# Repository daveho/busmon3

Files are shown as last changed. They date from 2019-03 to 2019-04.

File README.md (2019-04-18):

# busmon3: Breadboard-friendly 16 bit hex display

`busmon3` is a 16 bit hex display designed to plug into standard 830 contact solderless breadboards.  It's useful for microcomputer projects and similar because it allows you to see the value being driven on a 16 bit bus.

Obligatory action shot (click for full size):

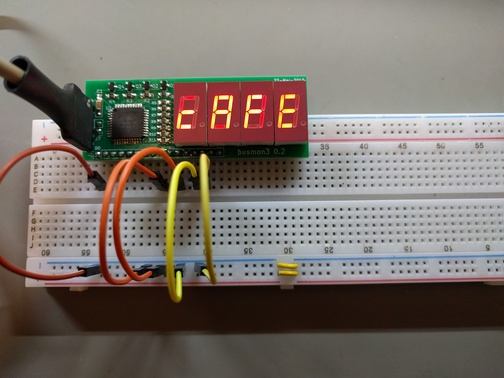
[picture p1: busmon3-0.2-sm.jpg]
Picture of busmon3


I got the idea from Quinn Dunki's [HexOut](http://quinndunki.com/blondihacks/?p=610) project.

The design is fairly brute force, but it does work.  The TQFN44 package of the atmega164a has 0.8mm pitch, which isn't too bad to hand-solder.  I have ordered boards from both [OSHPark](https://oshpark.com/) and [Seeed Studio](https://www.seeedstudio.com/fusion_pcb.html) and they work fine.

Note that the data inputs are pulled high (to VCC) by the atmega164a's internal pullup resistors.  You could change this in the firmware if you felt like it (e.g., because your bus already has external pullup or pulldown resistors.)

Also note that the board (1) is designed to sit at the top of an 830 contact breadboard, (2) assumes that VCC are GND are available on the breadboard's bus strips, and (3) assumes that the bottom bus strip is VCC.

# Parts needed

* atmega164a (TQFN44 package)
* 4 DIP14 package common anode 7 segment LED displays (MAN3620A, LTS-4910AHR, or similar)
* 4 SOT-23 MMBT3906 transistors
* 1 0.1uF 0805 ceramic capacitor (for decoupling)
* 7 270 Ohm 0805 resistors (the schematic shows 330 Ohm, but the displays are driven at 1/4 duty)
* 4 4.7K Ohm 0805 resistors
* 2 pin 0.1" male pin header (for breadboard power connections)
* 6 pin 0.1" male pin header (AVR programming header)
* 16 pin 0.1" male pin header (for breadboard data connections)

You will need an AVR programmer to program the firmware to the atmega164a.

# License

All material is copyright (c) 2017–2019, [David Hovemeyer](mailto:david.hovemeyer@gmail.com).

The hardware design is made available under the [CERN Open Hardware License version 1.2](https://www.ohwr.org/project/cernohl/uploads/505f27c2a8a10e528b079be3c9d876c5/cern_ohl_v_1_2.txt).

The firmware is made available under the [MIT License](https://opensource.org/licenses/MIT).

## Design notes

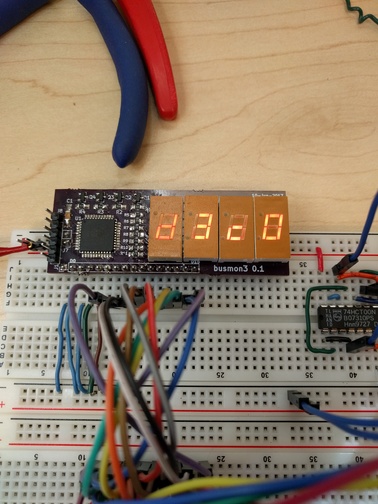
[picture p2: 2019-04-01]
busmon3-sm.jpg

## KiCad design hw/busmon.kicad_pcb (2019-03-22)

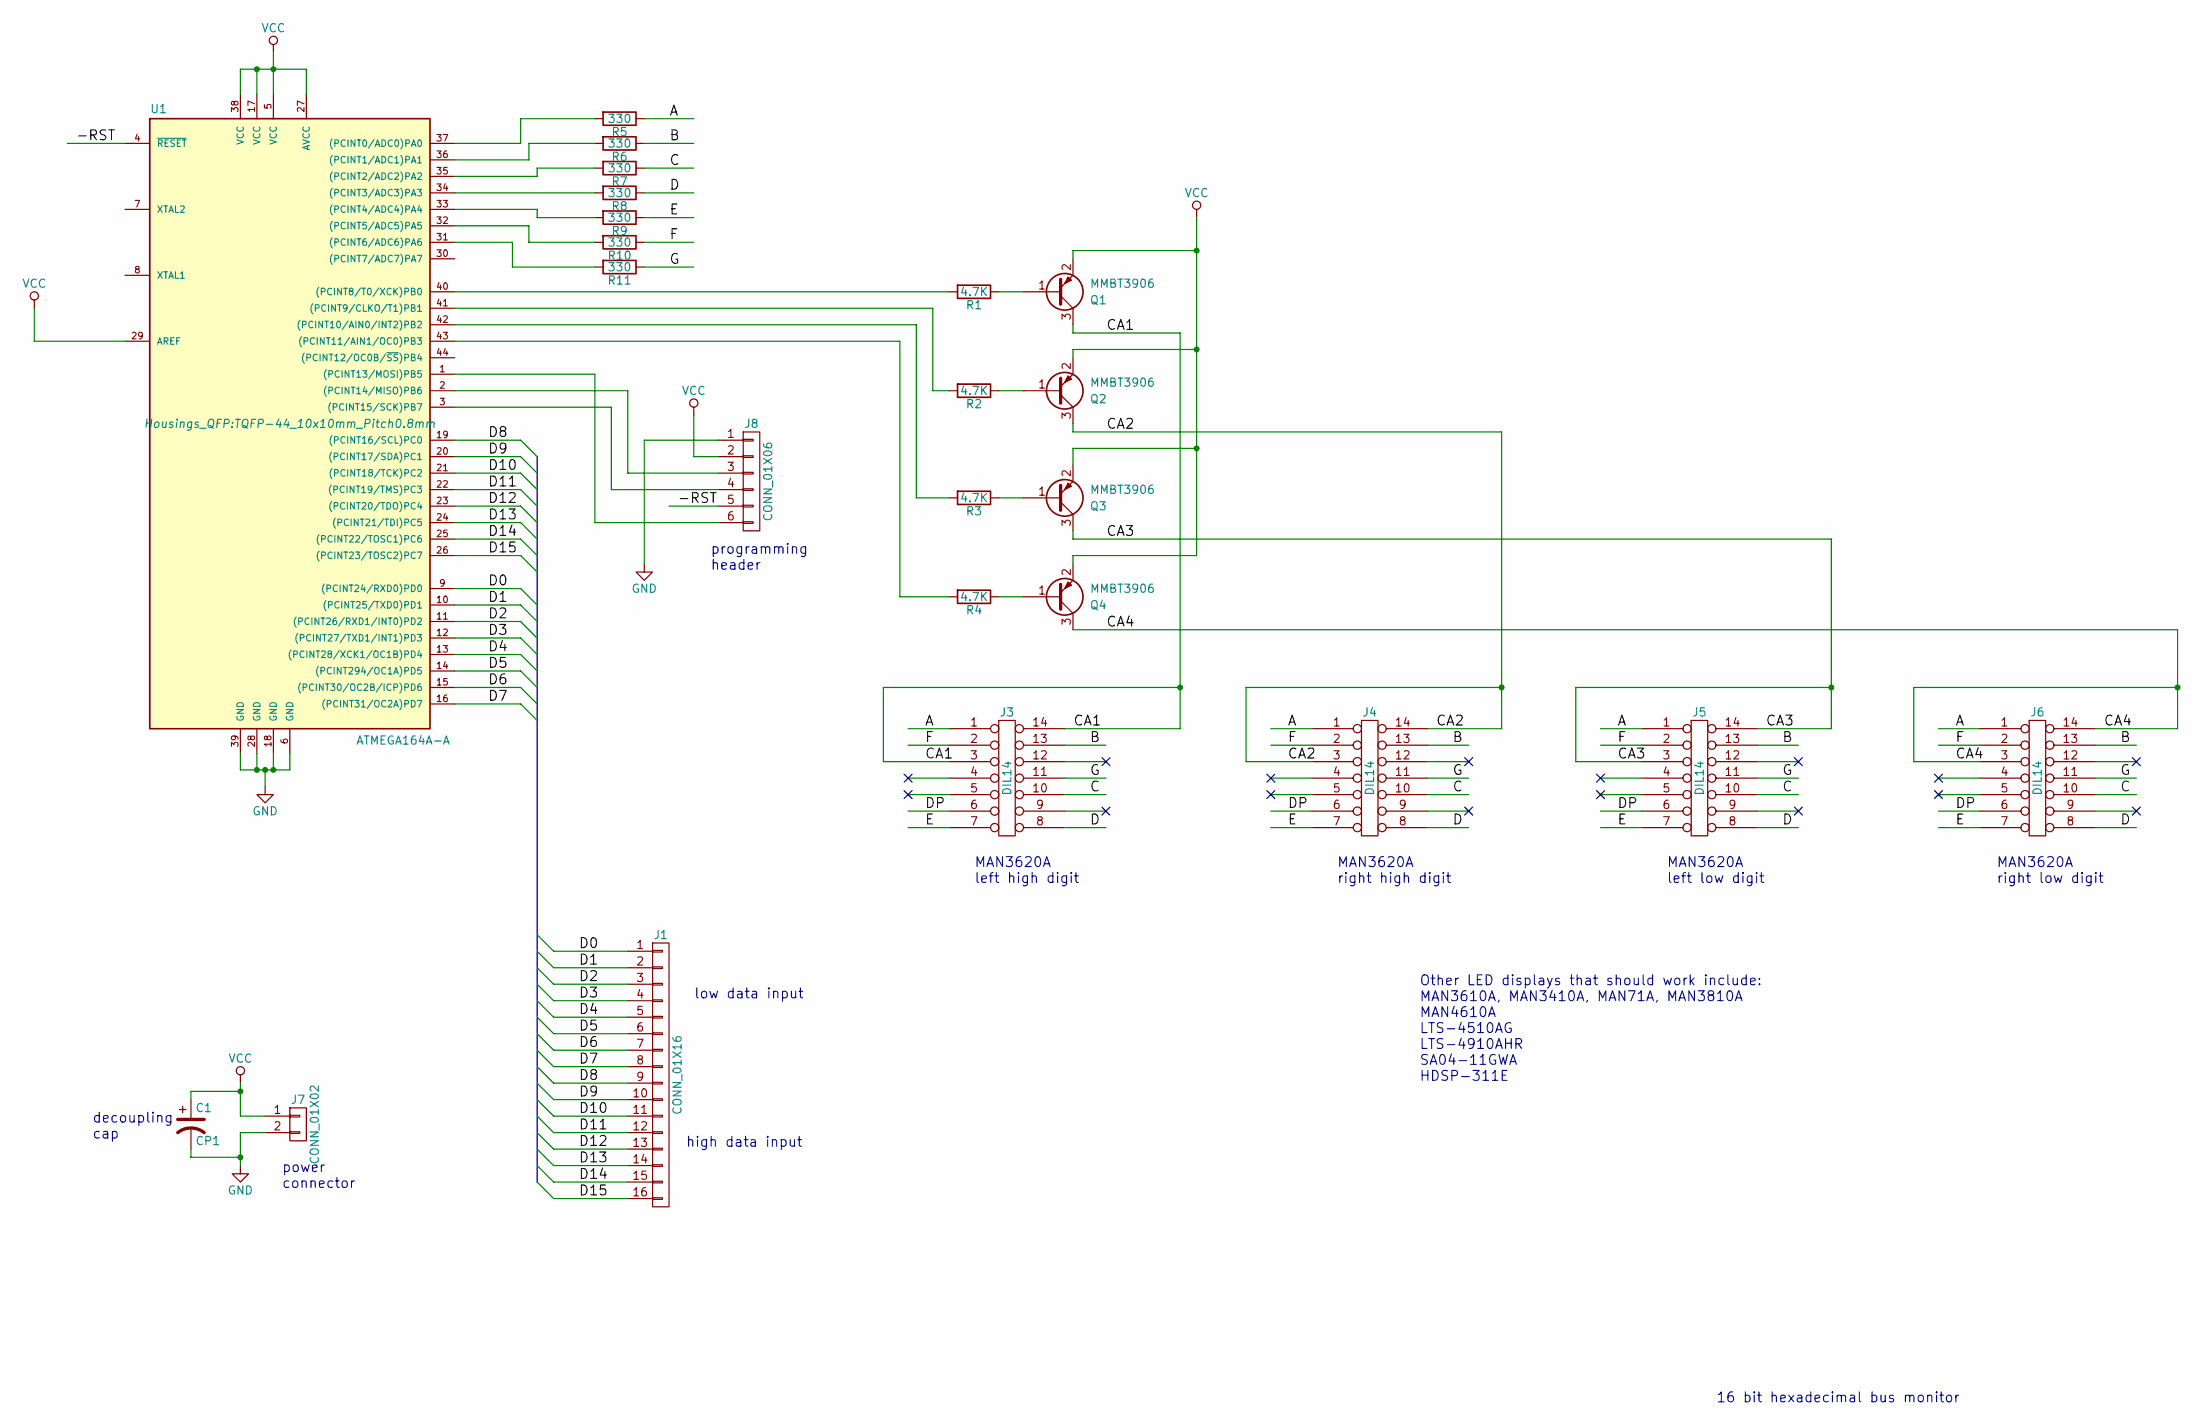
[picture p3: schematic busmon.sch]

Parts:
C1: CP1; CP_Tantalum_Case-A_EIA-3216-18_Hand
J1: CONN_01X16; Pin_Header_Straight_1x16_Pitch2.54mm
J3, J4, J5, J6: DIL14; DIP-14_W7.62mm
J7: CONN_01X02; Pin_Header_Straight_1x02_Pitch2.54mm
J8: CONN_01X06; Pin_Header_Straight_1x06_Pitch2.54mm
Q1, Q2, Q3, Q4: MMBT3906; SOT-23
R1, R2, R3, R4: 4.7K; R_0805_HandSoldering
R5, R6, R7, R8, R9, R10, R11: 330; R_0805_HandSoldering
U1: ATMEGA164A-A; TQFP-44_10x10mm_Pitch0.8mm

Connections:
/-RST: J8.5, U1.4 (~RESET)
/A: J3.1, J4.1, J5.1, J6.1, R5.1
/B: J3.13, J4.13, J5.13, J6.13, R6.1
/C: J3.10, J4.10, J5.10, J6.10, R7.1
/CA1: J3.3, J3.14, Q1.3 (C)
/CA2: J4.3, J4.14, Q2.3 (C)
/CA3: J5.3, J5.14, Q3.3 (C)
/CA4: J6.3, J6.14, Q4.3 (C)
/D: J3.8, J4.8, J5.8, J6.8, R8.1
/D0: J1.1, U1.9 ((PCINT24/RXD0)PD0)
/D1: J1.2, U1.10 ((PCINT25/TXD0)PD1)
/D2: J1.3, U1.11 ((PCINT26/RXD1/INT0)PD2)
/D3: J1.4, U1.12 ((PCINT27/TXD1/INT1)PD3)
/D4: J1.5, U1.13 ((PCINT28/XCK1/OC1B)PD4)
/D5: J1.6, U1.14 ((PCINT294/OC1A)PD5)
/D6: J1.7, U1.15 ((PCINT30/OC2B/ICP)PD6)
/D7: J1.8, U1.16 ((PCINT31/OC2A)PD7)
/D8: J1.9, U1.19 ((PCINT16/SCL)PC0)
/D9: J1.10, U1.20 ((PCINT17/SDA)PC1)
/D10: J1.11, U1.21 ((PCINT18/TCK)PC2)
/D11: J1.12, U1.22 ((PCINT19/TMS)PC3)
/D12: J1.13, U1.23 ((PCINT20/TDO)PC4)
/D13: J1.14, U1.24 ((PCINT21/TDI)PC5)
/D14: J1.15, U1.25 ((PCINT22/TOSC1)PC6)
/D15: J1.16, U1.26 ((PCINT23/TOSC2)PC7)
/DP: J3.6, J4.6, J5.6, J6.6
/E: J3.7, J4.7, J5.7, J6.7, R9.1
/F: J3.2, J4.2, J5.2, J6.2, R10.1
/G: J3.11, J4.11, J5.11, J6.11, R11.1
GND: C1.2, J7.2, J8.1, U1.6 (GND), U1.18 (GND), U1.28 (GND), U1.39 (GND)
unnamed: J8.3, U1.2 ((PCINT14/MISO)PB6)
unnamed: J8.4, U1.3 ((PCINT15/SCK)PB7)
unnamed: J8.6, U1.1 ((PCINT13/MOSI)PB5)
unnamed: Q1.1 (B), R1.1
unnamed: Q2.1 (B), R2.1
unnamed: Q3.1 (B), R3.1
unnamed: Q4.1 (B), R4.1
unnamed: R1.2, U1.40 ((PCINT8/T0/XCK)PB0)
unnamed: R2.2, U1.41 ((PCINT9/CLKO/T1)PB1)
unnamed: R3.2, U1.42 ((PCINT10/AIN0/INT2)PB2)
unnamed: R4.2, U1.43 ((PCINT11/AIN1/OC0)PB3)
unnamed: R5.2, U1.37 ((PCINT0/ADC0)PA0)
unnamed: R6.2, U1.36 ((PCINT1/ADC1)PA1)
unnamed: R7.2, U1.35 ((PCINT2/ADC2)PA2)
unnamed: R8.2, U1.34 ((PCINT3/ADC3)PA3)
unnamed: R9.2, U1.33 ((PCINT4/ADC4)PA4)
unnamed: R10.2, U1.32 ((PCINT5/ADC5)PA5)
unnamed: R11.2, U1.31 ((PCINT6/ADC6)PA6)
VCC: C1.1, J7.1, J8.2, Q1.2 (E), Q2.2 (E), Q3.2 (E), Q4.2 (E), U1.5 (VCC), U1.17 (VCC), U1.27 (AVCC), U1.29 (AREF), U1.38 (VCC)

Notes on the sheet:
MAN3620A left high digit
MAN3620A right high digit
16 bit hexadecimal bus monitor
power connector
low data input
MAN3620A left low digit
MAN3620A right low digit
high data input
decoupling cap
programming header
Other LED displays that should work include: MAN3610A, MAN3410A, MAN71A, MAN3810A MAN4610A LTS-4510AG LTS-4910AHR SA04-11GWA HDSP-311E

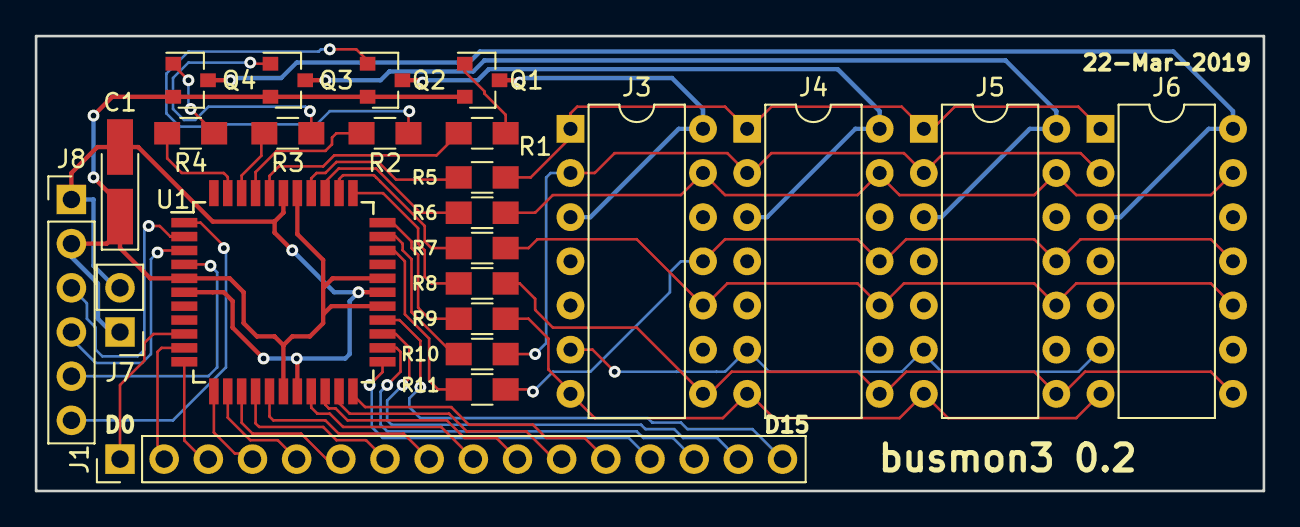
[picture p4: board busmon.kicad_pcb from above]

Board: 2 copper layers, 70.6 x 26.2 mm, 24 parts (0 on the bottom side), 49 nets.

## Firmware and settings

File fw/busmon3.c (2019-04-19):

// busmon3 firmware
// Copyright (c) 2017-2019, David H. Hovemeyer <david.hovemeyer@gmail.com>
//
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
#define F_CPU 1000000 // use internal oscillator, set to 1 MHz
#include <stdint.h>
#include <avr/io.h>
#include <avr/interrupt.h>
#include <util/delay.h>

// Comment this out to use hard-coded loop rather than timer
#define USE_TIMER

#define A (1<<0)
#define B (1<<1)
#define C (1<<2)
#define D (1<<3)
#define E (1<<4)
#define F (1<<5)
#define G (1<<6)

const uint8_t g_hexfont[16] = {
	~(A|B|C|D|E|F),
	~(B|C),
	~(A|B|D|E|G),
	~(A|B|C|D|G),
	~(B|C|F|G),
	~(A|C|D|F|G),
	~(A|C|D|E|F|G),
	~(A|B|C),
	~(A|B|C|D|E|F|G),
	~(A|B|C|F|G),
	~(A|B|C|E|F|G),
	~(C|D|E|F|G),
	~(D|E|G),
	~(B|C|D|E|G),
	~(A|D|E|F|G),
	~(A|E|F|G),
};

uint8_t g_count;

void update_display(void) {
	uint8_t which = g_count & 0x3;
	uint8_t val;
	switch (which) {
	case 0: // left high
		val = (PINC >> 4) & 0x0f;
		PORTB = ~1;
		PORTA = g_hexfont[val];
		break;
	case 1: // left low
		val = PINC & 0x0f;
		PORTB = ~2;
		PORTA = g_hexfont[val];
		break;
	case 2: // right high
		val = (PIND >> 4) & 0x0f;
		PORTB = ~4;
		PORTA = g_hexfont[val];
		break;
	case 3: // right low
		val = PIND & 0x0f;
		PORTB = ~8;
		PORTA = g_hexfont[val];
		break;
	}
	g_count++;
}

#ifdef USE_TIMER
ISR(TIMER0_OVF_vect) {
	update_display();
}
#endif

int main(void) {
	// disable JTAG, otherwise port C pins won't work correctly
	MCUCR |= (1 << JTD);
	MCUCR |= (1 << JTD);

	DDRA = 0xff;
	PORTA = 0xff; // all segments off initially
	DDRB = 0x0f;  // all displays off initially
	PORTB = 0xf0; // enable pull-ups on unused pins
	DDRC = 0x00;
	PORTC = 0xff; // enable pull-ups
	DDRD = 0x00;
	PORTD = 0xff; // enable pull-ups

#ifdef USE_TIMER
	// Set up timer interrupt to fire 256 times per second
	TCCR0B |= (1 << CS01);
	TIMSK0 |= (1 << TOIE0);

	sei(); // enable interrupts
#endif

	for (;;) {
#ifndef USE_TIMER
		update_display();
		_delay_ms(1);
#endif
	}
}

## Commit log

2017-06-12 initial checkin
    [busmon.kicad_pcb, busmon.sch]
2017-06-12 connected components
    [busmon.sch]
2017-06-12 getting ready for pcb
    [busmon.sch]
2017-06-12 associate footprints
    [busmon.sch]
2017-06-12 use SOT23-3 for transistors
    [busmon.sch]
2017-06-12 use 1x16 header for data input
    [busmon.sch]
2017-06-12 label tweak
    [busmon.sch]
2017-06-12 use correct transistor pinout
    [busmon.sch]
2017-06-12 updated footprint associations
    [busmon.sch]
2017-06-12 fix transistor orientation
    [busmon.sch]
2017-06-12 initial component layout
    [busmon.kicad_pcb]
2017-06-12 started routing power connections
    [busmon.kicad_pcb]
2017-06-12 routing more signals
    [busmon.kicad_pcb]
2017-06-12 routed more signals
    [busmon.kicad_pcb]
2017-06-12 routed all signals
    [busmon.kicad_pcb]
2017-06-12 routed a few missed signals
    [busmon.kicad_pcb]
2019-03-10 disable JTAG
    This was all that was needed to get the device
    completely working! The stuck low values
    were due to the JTAG hardware preventing
    using bits 2..5 of PORTC as inputs.
    Also did a bit of code refactoring and cleanup.
    [busmon3.c]
2019-03-10 converted project to KiCad 5
    Hopefully the PCB is still good.
    [busmon.sch]
2019-03-22 improve schematic, minor silkscreen fixes
    [busmon.kicad_pcb, busmon.sch]
2019-04-01 get ready to make public
    [busmon.sch]
2019-04-18 note about using 270 Ohm resistors
